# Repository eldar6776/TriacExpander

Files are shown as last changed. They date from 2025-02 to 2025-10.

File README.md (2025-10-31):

# TriacExpander

**RS485 Adresabilni 16-kanalni Triac Ekspander**

## Opis

TriacExpander je hardverski modul i firmware rešenje koje omogućava upravljanje do 16 AC kanala putem RS485 komunikacije. Svaki kanal je kontrolisan pomoću triaka, što omogućava efikasno i bezbedno uključivanje/isključivanje AC potrošača. Adresabilnost modula omogućava povezivanje više ekspandera na istu RS485 magistralu.

## Funkcionalnosti

- **16 nezavisnih AC kanala** – svaki kanal se može pojedinačno uključiti ili isključiti
- **RS485 komunikacija** – robustan i pouzdan industrijski standard za serijsku komunikaciju na duže udaljenosti
- **Adresabilni moduli** – svaki ekspander ima sopstvenu adresu na mreži
- **Podrška za kaskadno povezivanje** – više modula može raditi zajedno
- **Jednostavna integracija** – lako se povezuje sa PLC-om, mikrokontrolerima (npr. Arduino, ESP32), ili PC aplikacijama

## Tehničke karakteristike

- **Napajanje:** 220V AC (za triac kanale), 12V DC (za logiku, zavisno od dizajna)
- **Komunikacija:** RS485 (Modbus RTU ili custom protokol)
- **Broj kanala:** 16
- **Tip triaka:** BT136 ili ekvivalent
- **Maksimalna struja po kanalu:** do 16A (zavisno od triaka i hlađenja)
- **Mikrokontroler:** [STM32F030C6T6]

## Uputstvo za korišćenje

1. **Povezivanje modula**
    - Priključite AC izlaze na željene potrošače (npr. lampe, pumpe, grejače)
    - Povežite RS485 magistralu sa master uređajem (PLC, PC, Arduino...)

2. **Podešavanje adrese**
    - Svaki modul ima jumper/switch za podešavanje adrese (npr. 1-15)
    - Adresa se mora razlikovati za svaki modul na mreži

3. **Komunikacija**
    - Koristite odgovarajući komandni set za uključivanje/isključivanje kanala:
        - `SET <ADRESA> <KANAL> <ON/OFF>`
        - Primer: `SET 02 05 ON` – uključuje kanal 5 na modulu sa adresom 02

4. **Integracija sa softverom**
    - Primer Arduino koda za upravljanje:
    ```cpp
    // Slanje komande preko RS485
    Serial.print("SET 01 03 ON\n");
    ```

## Primeri primene

- Automatizacija rasvete u industriji ili domaćinstvu
- Upravljački sistemi grejanja, ventilacije i klimatizacije (HVAC)
- Kontrola pumpi, ventilatora i drugih električnih uređaja

## Šema povezivanja

*(https://github.com/eldar6776/TriacExpander/blob/main/hw/DE-140824/DE-140824.pdf)*

## Kontakt & Podrška

Za pitanja, sugestije ili podršku, kontaktirajte autora putem GitHub Issues

---

**Napomena:** Prilikom povezivanja AC tereta, obavezno poštujte sigurnosne mere i preporučuje se rad stručnog lica!

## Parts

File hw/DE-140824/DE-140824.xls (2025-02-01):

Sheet: BOM Report
Bill of Materials |  |  | Bill of Materials For PCB Document [DE-140824.PcbDoc]
Source Data From: |  | DE-140824.PcbDoc
Project: |  | DE-140824.PrjPcb
Variant: |  | None
Creation Date: | 14. 8. 2024. | 20:08:16
Print Date: | 45518 | 45518.83924
Footprint | Comment | LibRef | Designator | Description | Quantity
0805 | C0805 | C0805 | C1, C4, C8, C13 | Ceramic Chip Capacitor - Standard | 4
0603 | C0603 | C0603 | C2, C3, C5, C7, C9, C10, C11, C12, C14, C15, C22, C23, C24, C25 | Ceramic Chip Capacitor - Standard | 14
0603 | 100nF | C0603 | C6, C19, C20, C21 | Ceramic Chip Capacitor - Standard | 4
CAPPR5-10X12.5 | 470uF | EKA00DC347E00 | C16, C17 | Aluminum Electrolytic Capacitor, Radial Style with Long Leads: 470uF, 25V | 2
CAPPR2-5X11 | 22uF | EKA00AA247F00 | C18 | Aluminum Electrolytic Capacitor, Radial Style with Long Leads: 47uF, 35V | 1
ONSC-TO-220-3-221A-07 | BTA08-600 | BTA08-600BW3G | D1, D2, D3, D4, D5, D6, D7, D8, D9, D10, D11, D12, D13, D14, D15, D16 | Triacs, Silicon Bidirectional Thyristor, 3-Pin TO-220, Pb-Free, Tube | 16
1.6X0.8X0.8 | LED0 | HSMB-C190 | D17 | Blue Surface Mount Chip LED, Blue | 1
1.6X0.8X0.8 | LED4 | HSMB-C190 | D18 | Blue Surface Mount Chip LED, Blue | 1
1.6X0.8X0.8 | LED8 | HSMB-C190 | D19 | Blue Surface Mount Chip LED, Blue | 1
1.6X0.8X0.8 | LED12 | HSMB-C190 | D20 | Blue Surface Mount Chip LED, Blue | 1
1.6X0.8X0.8 | LED1 | HSMB-C190 | D21 | Blue Surface Mount Chip LED, Blue | 1
1.6X0.8X0.8 | LED5 | HSMB-C190 | D22 | Blue Surface Mount Chip LED, Blue | 1
1.6X0.8X0.8 | LED9 | HSMB-C190 | D23 | Blue Surface Mount Chip LED, Blue | 1
1.6X0.8X0.8 | LED13 | HSMB-C190 | D24 | Blue Surface Mount Chip LED, Blue | 1
1.6X0.8X0.8 | LED2 | HSMB-C190 | D25 | Blue Surface Mount Chip LED, Blue | 1
1.6X0.8X0.8 | LED6 | HSMB-C190 | D26 | Blue Surface Mount Chip LED, Blue | 1
1.6X0.8X0.8 | LED10 | HSMB-C190 | D27 | Blue Surface Mount Chip LED, Blue | 1
1.6X0.8X0.8 | LED14 | HSMB-C190 | D28 | Blue Surface Mount Chip LED, Blue | 1
1.6X0.8X0.8 | LED3 | HSMB-C190 | D29 | Blue Surface Mount Chip LED, Blue | 1
1.6X0.8X0.8 | LED7 | HSMB-C190 | D30 | Blue Surface Mount Chip LED, Blue | 1
1.6X0.8X0.8 | LED11 | HSMB-C190 | D31 | Blue Surface Mount Chip LED, Blue | 1
1.6X0.8X0.8 | LED15 | HSMB-C190 | D32 | Blue Surface Mount Chip LED, Blue | 1
0402-A | BLM15AG121 | Chip inductor | L1, L2, L3 | SMD chip inductor | 3
TERMINAL BLOK 2 | RS485 | TERMINAL BLOK 2 | P1 | Terminal blok konektor 3,5 mm | 1
HDR1X9 | Header 9 | Header 9 | P2, P3, P15, P16 | Header, 9-Pin | 4
TERMINAL BLOK 3 |  | TERMINAL BLOK 3 | P4, P5, P6, P7, P8, P9 | 3 pinski terminal blok konektor | 6
HDR1X3 | ICSP | Header 3 | P10 | Header, 3-Pin | 1
HDR1X12 | Header 12 | Header 12 | P11, P12, P17, P18 | Header, 12-Pin | 4
HDR2X8 | Header 8X2 | Header 8X2 | P13, P19 | Header, 8-Pin, Dual row | 2
TERMINAL BLOK 2 | DC_IN | TERMINAL BLOK 2 | P14 | Terminal blok konektor 3,5 mm | 1
ERA-0603 | 10K | ERAV, ERA3Y, ERA3Y, ERA3Y | R1, R8, R10, R11 | Metal Film Thermosensitive Chip Resistor, 0.56 Ohm to 10k Ohm Range, 5% Tolerance, 0603 Size, 0.063 W, Rectangular Thick Film Chip Resistor, 10 Ohm to 330k Ohm Range, 0.1% and 0.5% Tolerance, 0603 Size, 0.063 W, Rectangular Thick Film Chip Resistor, 10 Oh | 4
ERA-0603 | 10R | ERAV | R2, R3 | Metal Film Thermosensitive Chip Resistor, 0.56 Ohm to 10k Ohm Range, 5% Tolerance, 0603 Size, 0.063 W | 2
ERA-0603 | 1K2 | ERAV | R4 | Metal Film Thermosensitive Chip Resistor, 0.56 Ohm to 10k Ohm Range, 5% Tolerance, 0603 Size, 0.063 W | 1
ERA-0603 | 2K2 | ERAV, ERA3Y, ERA3Y | R5, R6, R7 | Metal Film Thermosensitive Chip Resistor, 0.56 Ohm to 10k Ohm Range, 5% Tolerance, 0603 Size, 0.063 W, Rectangular Thick Film Chip Resistor, 10 Ohm to 330k Ohm Range, 0.1% and 0.5% Tolerance, 0603 Size, 0.063 W, Rectangular Thick Film Chip Resistor, 10 Oh | 3
ERA-0603 | 100R | ERAV | R9, R12 | Metal Film Thermosensitive Chip Resistor, 0.56 Ohm to 10k Ohm Range, 5% Tolerance, 0603 Size, 0.063 W | 2
ERA-0603 | 220R | ERA3Y, ERA3Y, ERA3Y, ERA3Y, ERA3Y, ERA3Y, ERA3Y, ERA3Y, ERA3Y, ERA3Y, ERA3Y, ERA3Y, ERA3Y, ERA3Y, ERA3Y, ERA3Y, ERAS, ERAS, ERAS, ERAS | R13, R17, R23, R27, R33, R37, R43, R47, R53, R57, R63, R67, R73, R77, R83, R87, R93, R94, R95, R96 | Rectangular Thick Film Chip Resistor, 10 Ohm to 330k Ohm Range, 0.1% and 0.5% Tolerance, 0603 Size, 0.063 W, Rectangular Thick Film Chip Resistor, 10 Ohm to 330k Ohm Range, 0.1% and 0.5% Tolerance, 0603 Size, 0.063 W, Rectangular Thick Film Chip Resistor, | 20
ERA-0805 | 120R | ERAS | R14, R15, R16, R18, R19, R20, R24, R25, R26, R28, R29, R30, R34, R35, R36, R38, R39, R40, R44, R45, R46, R48, R49, R50, R54, R55, R56, R58, R59, R60, R64, R65, R66, R68, R69, R70, R74, R75, R76, R78, R79, R80, R84, R85, R86, R88, R89, R90 | Metal Film Thermosensitive Chip Resistor, 0.56 Ohm to 10k Ohm Range, 5% Tolerance, 0805 Size, 0.1 W | 48
ERA-0805 | 330R | ERAS | R21, R22, R31, R32, R41, R42, R51, R52, R61, R62, R71, R72, R81, R82, R91, R92 | Metal Film Thermosensitive Chip Resistor, 0.56 Ohm to 10k Ohm Range, 5% Tolerance, 0805 Size, 0.1 W | 16
DIP-12/SW | SW DIP-6 | SW DIP-6 | S1 | DIP Switch, 6 Position, SPST | 1
TACTILE_SWITCH | MOVE | TACKTILE_SWITCH | S2 |  | 1
TACTILE_SWITCH | FUNC | TACKTILE_SWITCH | S3 |  | 1
STM-LQFP48_N | STM32F030C6T6 | STM32F030C6T6 | U1 | ARM Cortex-M0 32-bit MCU, 32 KB Flash, 4 KB Internal RAM, 39 I/Os, 48-pin LQFP, -40 to 85 degC, Tray | 1
D008_N | SN75176BD | SN75176BD | U2 | Differential Bus Transceiver | 1
SOT-23-OT5_N | 24AA01T-I/OT | 24AA01T-I/OT | U3 | 1Kbit, 400kHz, 1.8V, I2C Serial EEPROM, 5-Pin SOT-23, Industrial Temperature, Tape and Reel | 1
DBZ3_N | TLV803MDBZR | TLV803MDBZR | U4 | Voltage Supervisor with Active-Low, Open Drain Reset, 1 Supply Monitored, -40 to 125 degC, 3-pin SOT-23 (DBZ), Green (RoHS & no Sb/Br) | 1
SOIC-SN8_N | MCS1802GS-10-Z | ACS71240 | U5, U7 |  | 2
TO220 | L7805CV | L7805CV | U6 | Positive Voltage Regulator, 5V, 3-Pin TO-220 | 1
ZZ311 | REG1117-3.3 | REG1117-3.3 | U8 | 800mA and 1A Low Dropout Positive Regulator 2.85V, 3.3V, 5V, and Adjustable | 1
DIP6 | MOC3081 | MOC3081 | U9, U10, U11, U12, U13, U14, U15, U16, U17, U18, U19, U20, U21, U22, U23, U24 | Zero-Cross Optoisolator Triac Driver | 16
 |  |  |  |  | 202
Approved |  | Notes

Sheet: Project Information
Project Full Path | D:\ProjektiOtvoreni\Expanderi\TriacExpander\DE-140824\DE-140824.PrjPcb
Project Filename | DE-140824.PrjPcb
Variant Name | None
Data-Source Filename | DE-140824.PcbDoc
Data-Source Full Path | D:\ProjektiOtvoreni\Expanderi\TriacExpander\DE-140824\DE-140824.PcbDoc
Title | Bill of Materials For PCB Document [DE-140824.PcbDoc]
Total Quantity | 202
Report Time | 20:08:16
Report Date | 14. 8. 2024.
Report Date & Tine | 14. 8. 2024. 20:08:16
Output Name | Bill of Materials
Output Type | BOM_PartType
Output Generator Name | BOM
Output Generator Description | Bill of Materials

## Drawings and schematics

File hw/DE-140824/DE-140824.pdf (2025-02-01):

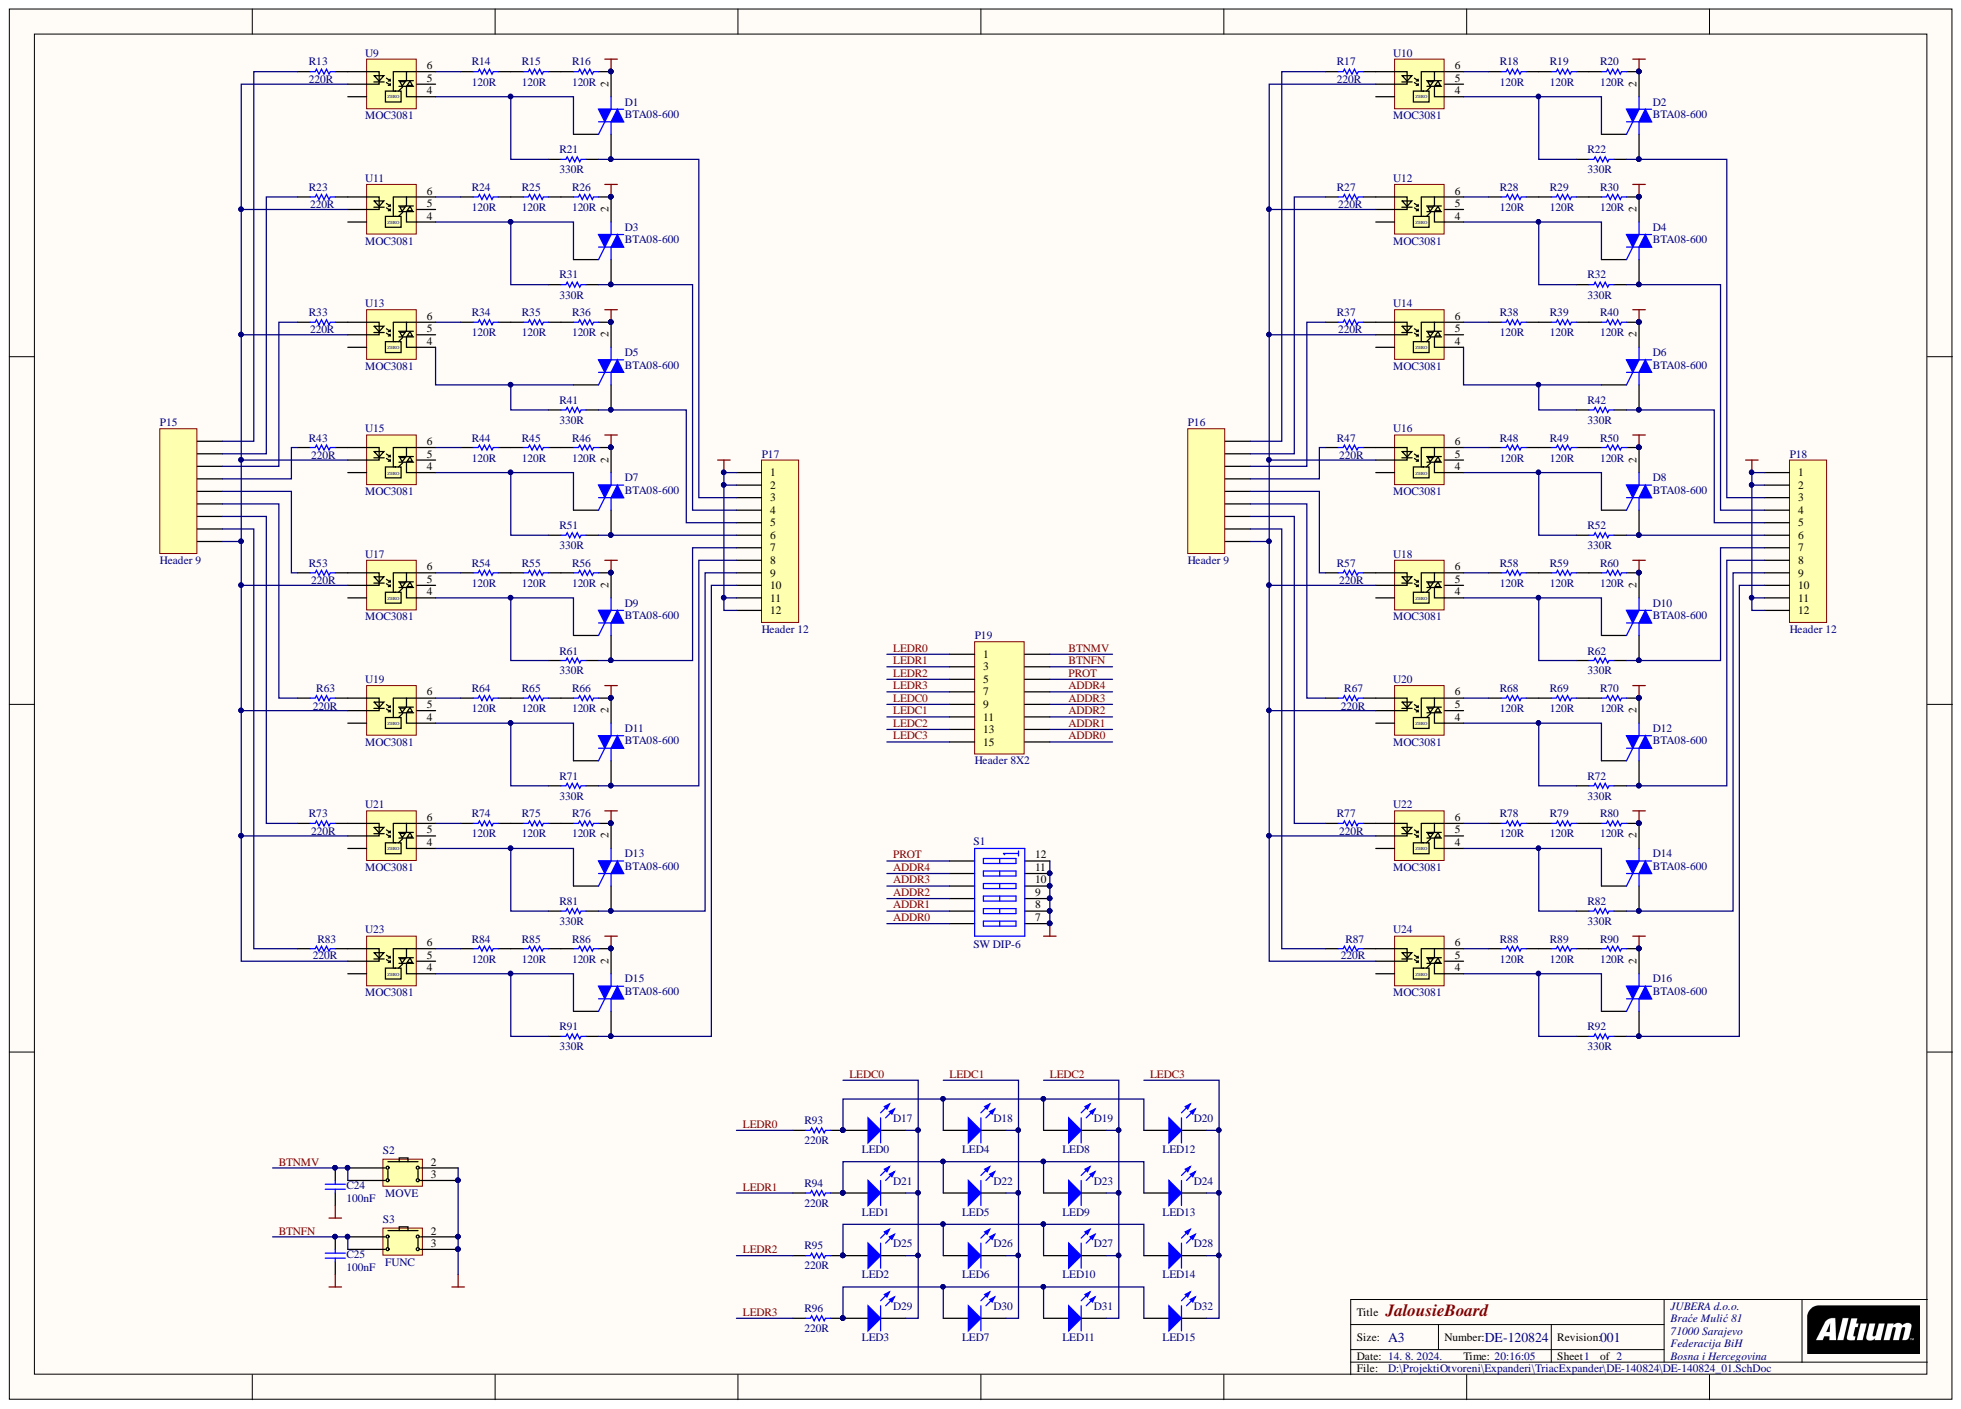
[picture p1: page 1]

JalousieBoard Title | JUBERA d.o.o. Braće Mulić 81 71000 Sarajevo Federacija BiH Bosna i Hercegovina

Size: A3 | Number: DE-120824 | Revision: 001
Date: 14. 8. 2024. Time: 20:16:05 | | Sheet of 2

D:\ProjektiOtvoreni\Expanderi\TriacExpander\DE-140824\DE-140824_01.SchDoc

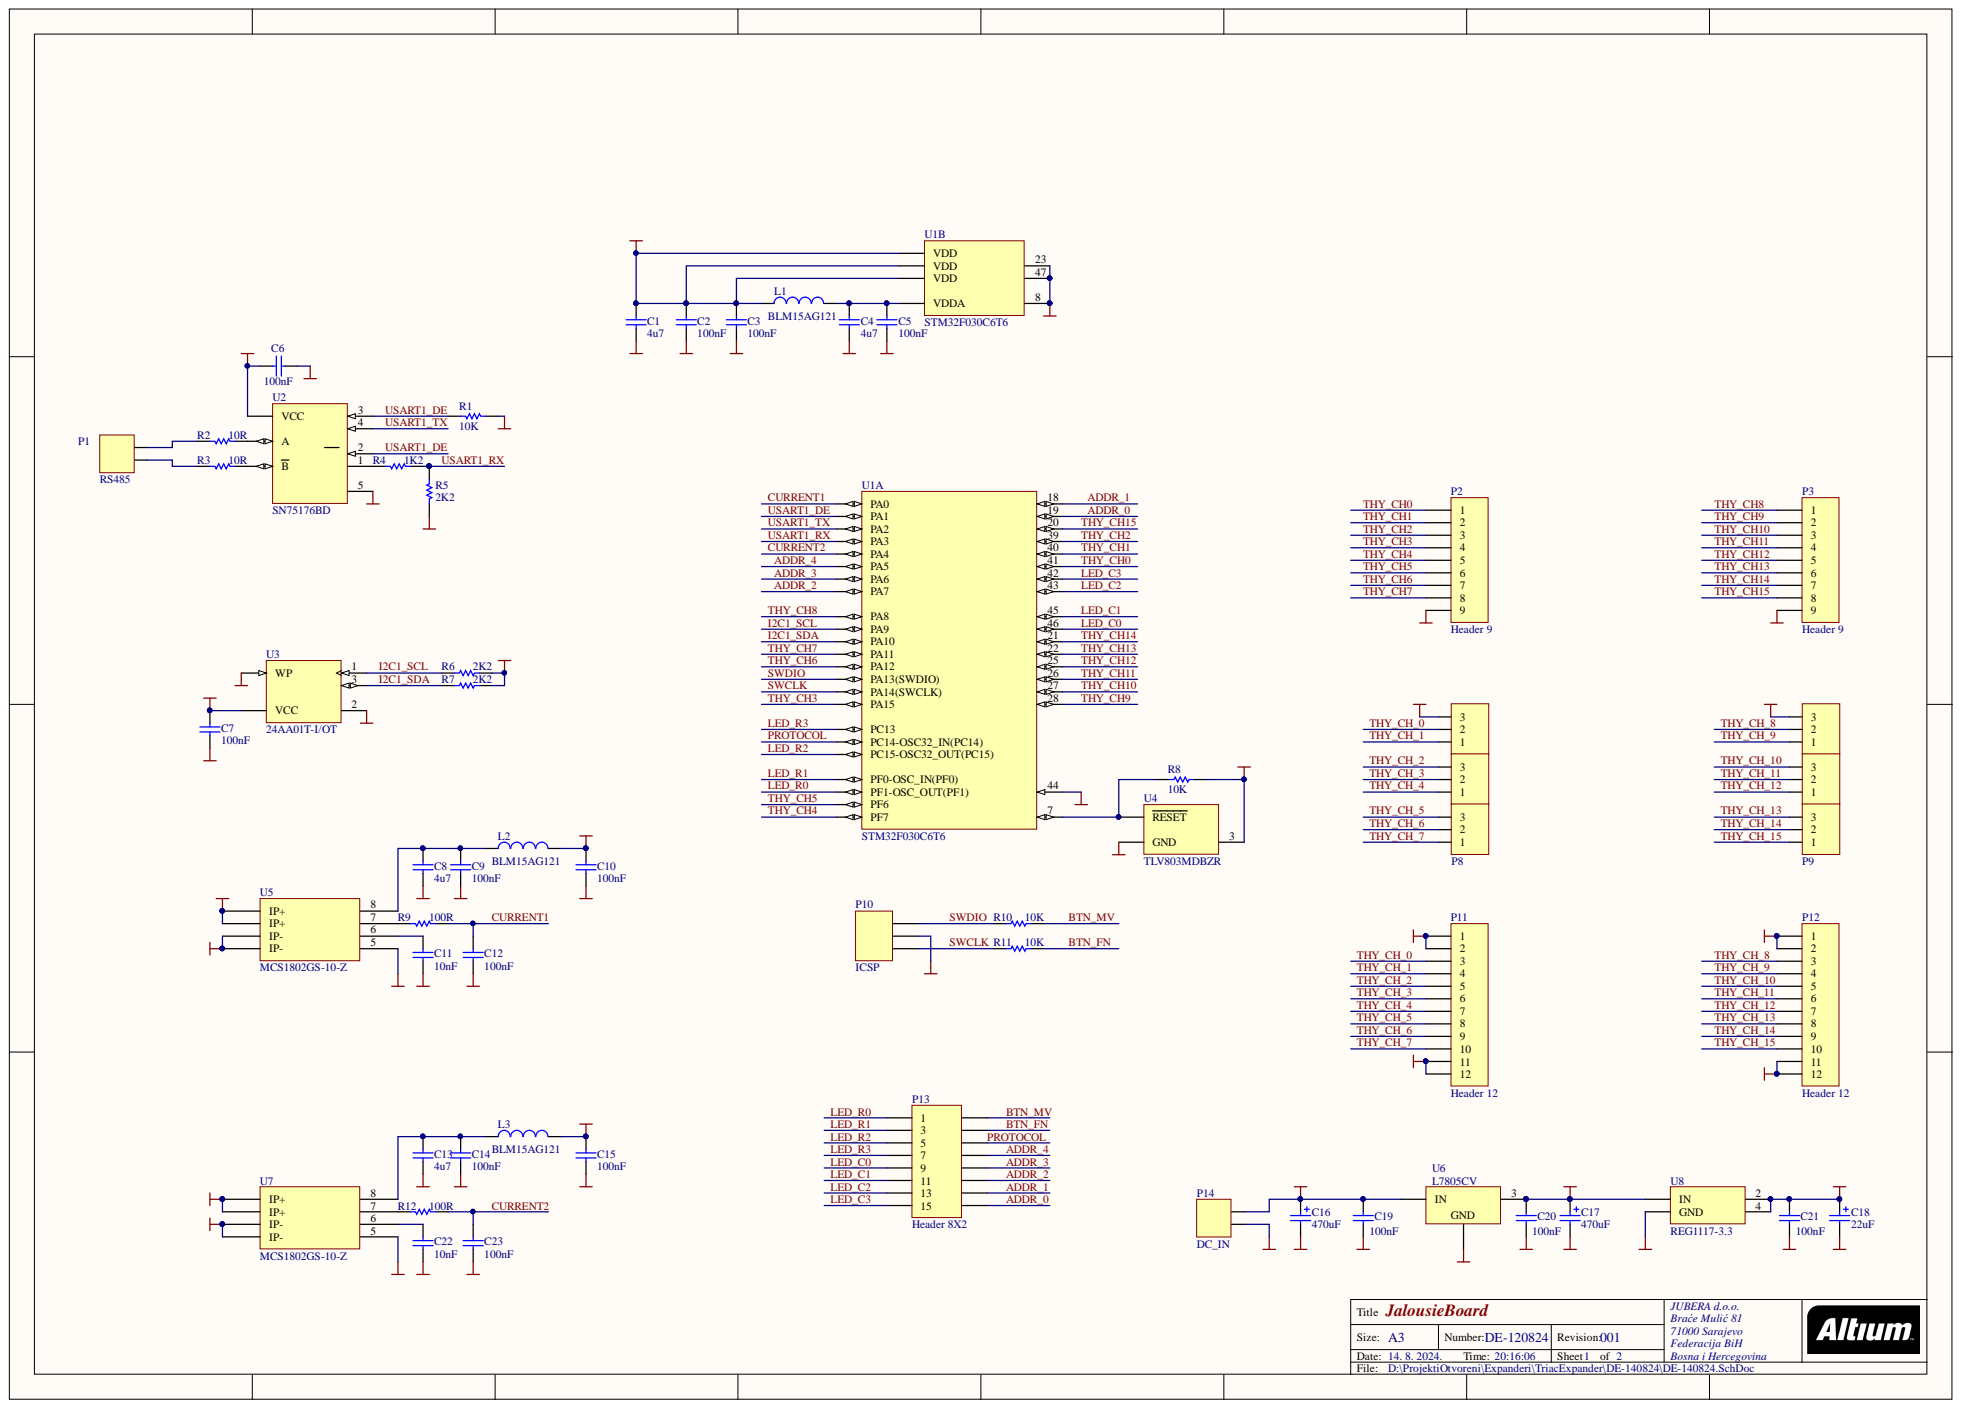
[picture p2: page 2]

Jalou s i Ti t l e | JUB ERA d.o.o. B r a će Mul i ć 81 71000 Sarajevo Federacija BiH Bosna i Hercegovina

Size: A | Number : E-120824 | Revi s ion: 001
Date: Ti me: | | Sheet of

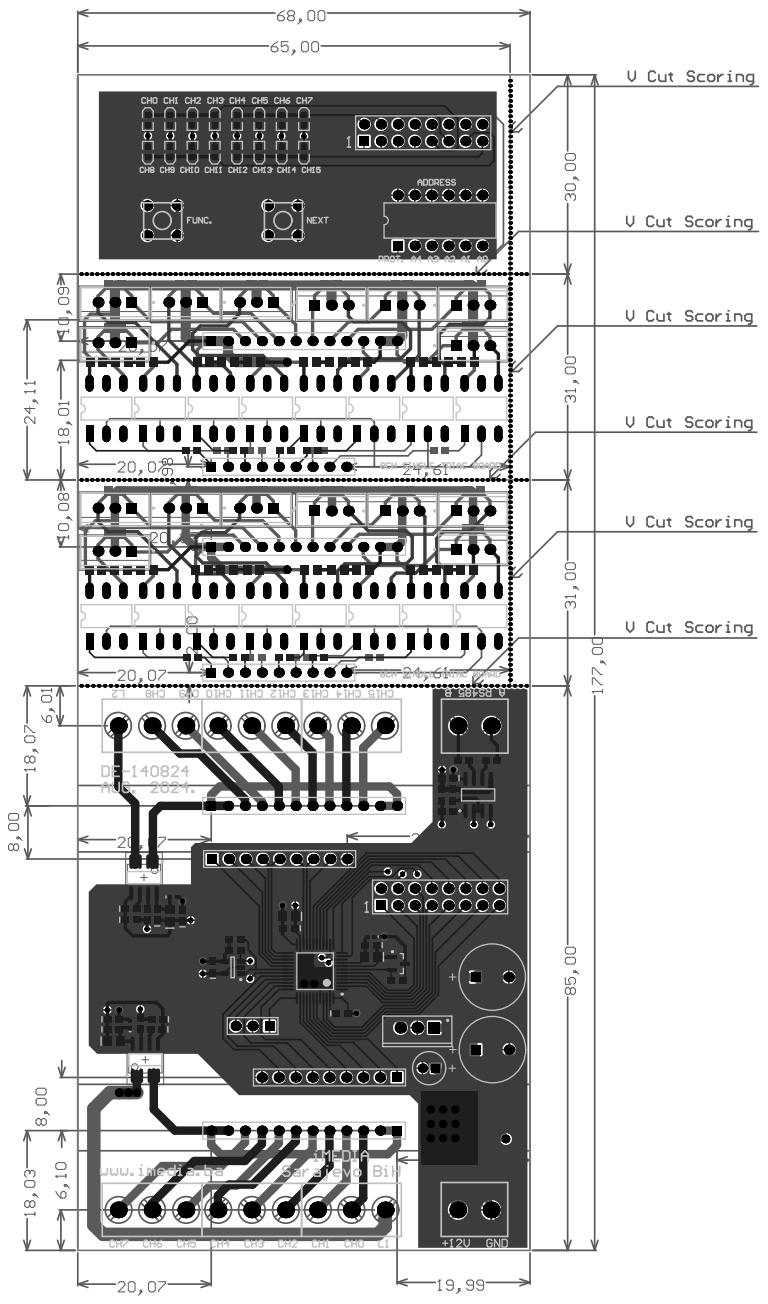
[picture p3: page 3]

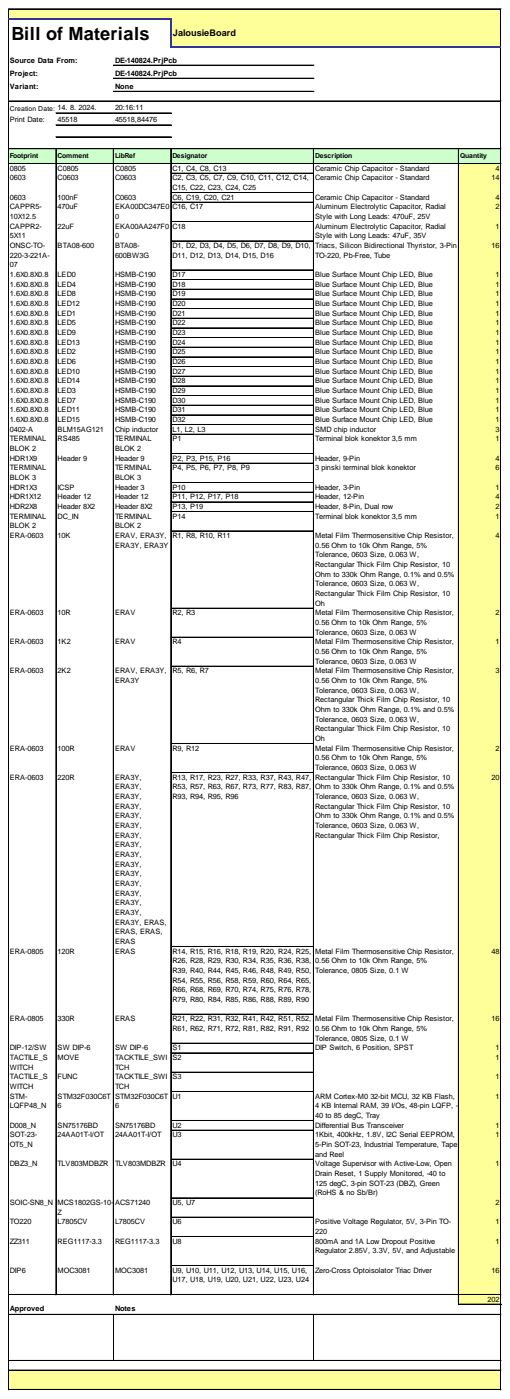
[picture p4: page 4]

Style with Long Leads: 470uF, 25V

Style with Long Leads: 47uF, 35V
Triacs, Silicon Bidirectional Thyristor, 3-Pin
TO-220, Pb-Free, Tube

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

Tolerance, 0603 Size, 0.063 W

Rectangular Thick Film Chip Resistor,

Metal Film Thermosensitive Chip Resistor,
Tolerance, 0805 Size, 0.1 W

4 KB Internal RAM, 39 I/Os, 48-pin LQFP, -
40 to 85 degC, Tray

5-Pin SOT-23, Industrial Temperature, Tape
and Reel

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

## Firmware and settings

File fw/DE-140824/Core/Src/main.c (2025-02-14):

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
/* Includes ------------------------------------------------------------------*/
#include "main.h"

/* USER CODE BEGIN Includes */
#include <stdio.h>
#include <string.h>
#include <stdarg.h>
#include <stdlib.h>
/* USER CODE END Includes */

/* USER CODE BEGIN PD */
#define NUMBER_OF_TRIAC 16
#define SNAKE_LENGTH 4  // Dužina zmije
#define SNAKE_SPEED 20   // Brzina zmije (veća vrednost = sporije)
#define MENU_TIMEOUT    10000 // 10 sekundi timeout
#define BUTTON_PAUSE    200 // dodatni debouncing
#define TOGGLE_INTERVAL 50 // Period treptanja LED
/* USER CODE END PD */

ADC_HandleTypeDef hadc;

CRC_HandleTypeDef hcrc;

I2C_HandleTypeDef hi2c1;

IWDG_HandleTypeDef hiwdg;

TIM_HandleTypeDef htim14;

UART_HandleTypeDef huart1;

/* USER CODE BEGIN PV */
GPIO_TypeDef *TRIAC_PORT[NUMBER_OF_TRIAC] = {GPIOB, GPIOB, GPIOB, GPIOA, GPIOF, GPIOF, GPIOA, GPIOA, GPIOA, GPIOB, GPIOB, GPIOB, GPIOB, GPIOB, GPIOB, GPIOB};
uint16_t GATE_PIN[NUMBER_OF_TRIAC] = {GPIO_PIN_5, GPIO_PIN_4, GPIO_PIN_3, GPIO_PIN_15, GPIO_PIN_7, GPIO_PIN_6 ,GPIO_PIN_12 ,GPIO_PIN_11, GPIO_PIN_8, \
                        GPIO_PIN_15, GPIO_PIN_14, GPIO_PIN_13, GPIO_PIN_12, GPIO_PIN_11, GPIO_PIN_10, GPIO_PIN_2};

volatile uint8_t snake_head = 0;  // Trenutna glava zmije
volatile uint8_t snake_counter = 0;  // Brojač za usporavanje

// Stanje LED dioda (simulacija konstante, treba postavljati u aplikaciji)
volatile uint8_t led_states[NUMBER_OF_TRIAC] = {0};
volatile uint8_t triac_states[NUMBER_OF_TRIAC] = {0};  // Trenutnostanje releja

// Trenutno aktivni red
volatile uint8_t active_row = 0;

volatile uint32_t last_press_time = 0;
volatile uint32_t menu_timer = 0;
volatile uint32_t last_toggle_time = 0;
volatile uint8_t toggle_state = 0;
volatile uint8_t menu_activ = 0;
volatile uint8_t selected_channel = NUMBER_OF_TRIAC - 1;
volatile uint8_t button_select_prev = 0, button_onoff_prev = 0;
volatile uint8_t my_address = 0;
volatile uint8_t first_toggle = 1;
volatile uint16_t triac_start = 0;
volatile uint16_t triac_end = 0;
bool init_tf = false;
bool restart = false;
bool setup_mod = false;
uint8_t rec;
TinyFrame tfapp;
/* USER CODE END PV */

void SystemClock_Config(void);
static void MX_GPIO_Init(void);
static void MX_ADC_Init(void);
static void MX_I2C1_Init(void);
static void MX_IWDG_Init(void);
static void MX_USART1_UART_Init(void);
static void MX_CRC_Init(void);
static void MX_TIM14_Init(void);
/* USER CODE BEGIN PFP */
void RS485_Init(void);
/* USER CODE END PFP */

/* USER CODE BEGIN 0 */
/**
  * @brief  staticka inline funkcija pauze 1~2ms za kašnjenje odgovora za stabilne repeatere
  *         u interruptu se ne može koristiti HAL_GetTick ni HAL_Delay tako da ova funkcija
  *         obezbjeduje kašnjenje oko 1 ms bez hal drivera gubljenjem vremena izvršavanjem 
  *         ciklusa koji ne rade ništa
  * @param
  * @retval
  */
static inline void delay_us(uint32_t us) {
    volatile uint32_t cycles = (HAL_RCC_GetHCLKFreq() / 20000000) * us;  // Smanjen faktor
    while (cycles--) {                                  
        __asm volatile("NOP");  // Izbegava optimizaciju
    }
}
/**
  * @brief Podesi rs485 adresu  uređaja prema poziciji DIP sitcheva
  * @retval None
  */
void get_address(void)
{
    my_address = 0;
    if ((HAL_GPIO_ReadPin(ADDRESS0_GPIO_Port, ADDRESS0_Pin) == GPIO_PIN_RESET))   my_address |= 0x20;
    if ((HAL_GPIO_ReadPin(ADDRESS1_GPIO_Port, ADDRESS1_Pin) == GPIO_PIN_RESET))   my_address |= 0x10;
    if ((HAL_GPIO_ReadPin(ADDRESS2_GPIO_Port, ADDRESS2_Pin) == GPIO_PIN_RESET))   my_address |= 0x08;
    if ((HAL_GPIO_ReadPin(ADDRESS3_GPIO_Port, ADDRESS3_Pin) == GPIO_PIN_RESET))   my_address |= 0x04;
    if ((HAL_GPIO_ReadPin(ADDRESS4_GPIO_Port, ADDRESS4_Pin) == GPIO_PIN_RESET))   my_address |= 0x02;
    if ((HAL_GPIO_ReadPin(ADDRESS5_GPIO_Port, ADDRESS5_Pin) == GPIO_PIN_RESET))   my_address |= 0x01;
    if(my_address)
    {
        triac_start = (NUMBER_OF_TRIAC*(my_address-1))+1;
        triac_end = triac_start + NUMBER_OF_TRIAC - 1;
    }
}
/**
  * @brief LED efect for settings menu
  * @retval None
  */
void update_snake(void) 
{
    if (++snake_counter < SNAKE_SPEED) {
        return;  // Čekamo dok ne prođe dovoljno ciklusa
    }
    snake_counter = 0;  // Reset brojača

    // Očisti prethodno stanje LED-ova
    for (uint8_t i = 0; i < 16; i++) {
        led_states[i] = 0;  // Privremeno uklanjamo const
    }

    // Podesi svetleće LED-ove
    for (uint8_t i = 0; i < SNAKE_LENGTH; i++) {
        int8_t pos = snake_head - i;
        if (pos < 0) pos += 16;  // Omogućava kružno kretanje po matrici
        led_states[pos] = 1;  // Upali LED
    }

    // Pomeraj zmiju napred
    snake_head = (snake_head + 1) % 16;
}
/**
  * @brief Refresh triac gate outputs
  * @retval None
  */
void set_triac(void)
{
    // Samo proleti kroz sve izlaze i postavi stanje prema baferu
    for (uint8_t i = 0; i < NUMBER_OF_TRIAC; i++)
    {
        HAL_GPIO_WritePin(TRIAC_PORT[i], GATE_PIN[i], (triac_states[i] > 0) ? GPIO_PIN_SET : GPIO_PIN_RESET);
    }
}
/**
  * @brief Copy triac states to LED
  * @retval None
  */
void refresh_led(void)
{
    // Samo kopiraj izlaze na LED
    for (uint8_t i = 0; i < NUMBER_OF_TRIAC; i++)
    {
        led_states[i] = triac_states[i];
    }
}
/**
  * @brief Funkcija za osvežavanje LED matrice
  * @retval None
  */
void refresh_led_matrix(void) 
{
    // Isključi trenutno aktivni red
    HAL_GPIO_WritePin(LED_R0_GPIO_Port, LED_R0_Pin, GPIO_PIN_RESET);
    HAL_GPIO_WritePin(LED_R1_GPIO_Port, LED_R1_Pin, GPIO_PIN_RESET);
    HAL_GPIO_WritePin(LED_R2_GPIO_Port, LED_R2_Pin, GPIO_PIN_RESET);
    HAL_GPIO_WritePin(LED_R3_GPIO_Port, LED_R3_Pin, GPIO_PIN_RESET);

    // Očisti kolone
    HAL_GPIO_WritePin(LED_C0_GPIO_Port, LED_C0_Pin, GPIO_PIN_SET);
    HAL_GPIO_WritePin(LED_C1_GPIO_Port, LED_C1_Pin, GPIO_PIN_SET);
    HAL_GPIO_WritePin(LED_C2_GPIO_Port, LED_C2_Pin, GPIO_PIN_SET);
    HAL_GPIO_WritePin(LED_C3_GPIO_Port, LED_C3_Pin, GPIO_PIN_SET);

    // Aktiviraj sledeći red
    switch (active_row) {
    case 0:
        HAL_GPIO_WritePin(LED_R0_GPIO_Port, LED_R0_Pin, GPIO_PIN_SET);
        break;
    case 1:
        HAL_GPIO_WritePin(LED_R1_GPIO_Port, LED_R1_Pin, GPIO_PIN_SET);
        break;
    case 2:
        HAL_GPIO_WritePin(LED_R2_GPIO_Port, LED_R2_Pin, GPIO_PIN_SET);
        break;
    case 3:
        HAL_GPIO_WritePin(LED_R3_GPIO_Port, LED_R3_Pin, GPIO_PIN_SET);
        break;
    }

    // Postavi kolone na osnovu led_state[] tako da se kolone i redovi zamjene
    for (uint8_t row = 0; row < 4; row++) {
        uint8_t index = row * 4 + active_row;  // Zamjeni red i kolonu
        if (led_states[index]) {
            switch (row) {
            case 0:
                HAL_GPIO_WritePin(LED_C0_GPIO_Port, LED_C0_Pin, GPIO_PIN_RESET);
                break;
            case 1:
                HAL_GPIO_WritePin(LED_C1_GPIO_Port, LED_C1_Pin, GPIO_PIN_RESET);
                break;
            case 2:
                HAL_GPIO_WritePin(LED_C2_GPIO_Port, LED_C2_Pin, GPIO_PIN_RESET);
                break;
            case 3:
                HAL_GPIO_WritePin(LED_C3_GPIO_Port, LED_C3_Pin, GPIO_PIN_RESET);
                break;
            }
        }
    }

    // Prebaci na sledeći red
    active_row = (active_row + 1) % 4;
}
/**
  * @brief Front panel taster button processing function
  * @retval None
  */
void handle_buttons(void)
{
    uint32_t current_time = HAL_GetTick();
    uint8_t button_select = HAL_GPIO_ReadPin(GPIOA, GPIO_PIN_14);
    uint8_t button_onoff = HAL_GPIO_ReadPin(GPIOA, GPIO_PIN_13);

    if (button_select == GPIO_PIN_RESET) {
        if (!button_select_prev) {
            button_select_prev = 1; // lock press time load
            menu_activ = 1;
            first_toggle = 1;
            if (++selected_channel >= NUMBER_OF_TRIAC) selected_channel = 0;
            toggle_state = triac_states[selected_channel]; // Resetuj toggle_state po novom kanalu
            menu_timer = current_time + MENU_TIMEOUT;
            last_press_time = current_time; // load first press time
            refresh_led();
            get_address(); // ponovo uzmi adresu
            HAL_Delay(BUTTON_PAUSE);
        }
    }
    else if ((button_select == GPIO_PIN_SET) && button_select_prev)
    {
        button_select_prev = 0;
        HAL_Delay(BUTTON_PAUSE);
        refresh_led();
    }

    if (menu_activ && (button_onoff == GPIO_PIN_RESET)) {
        if (!button_onoff_prev) {
            button_onoff_prev = 1; // lock press time load
            last_press_time = current_time; // load first press time
            triac_states[selected_channel] ^= 1; // Toggle stanja triaka

            // Resetujemo first_toggle i toggle_state kako bi ispravno započelo treperenje
            first_toggle = 1;
            toggle_state = triac_states[selected_channel]; 
            HAL_Delay(BUTTON_PAUSE);
            refresh_led();
        }
        menu_timer = current_time + MENU_TIMEOUT;
    }
    else if ((button_onoff == GPIO_PIN_SET) && button_onoff_prev)
    {
        button_onoff_prev = 0; // release button press
        HAL_Delay(BUTTON_PAUSE);
    }
}
/**
  * @brief Jednostavan meni za podešavanje stanja izlaza sa različitim odnosom pauze i signala
  *         odabrane LED prema stanju izlaza kraći signal duža pauza za isključen izlaz    
  * @retval None
  */
void menu_logic(void)
{
    uint32_t current_time = HAL_GetTick();

    // Resetujemo meni ako istekne vrijeme
    if (current_time > menu_timer) {
        selected_channel = NUMBER_OF_TRIAC - 1;
        menu_activ = 0;
        toggle_state = 0;
        refresh_led();
        first_toggle = 1;  // Resetuj first_toggle ako se resetuje meni
    }

    // Definiši vremenske intervale zavisno od triac_states
    uint32_t on_time, off_time;
    if (triac_states[selected_channel] == 1) {
        on_time = TOGGLE_INTERVAL * 5;  // LED ON duže
        off_time = TOGGLE_INTERVAL;     // LED OFF kraće
    } else {
        on_time = TOGGLE_INTERVAL;      // LED ON kraće
        off_time = TOGGLE_INTERVAL * 5; // LED OFF duže
    }

    // Pri prvom ulasku postavi početno stanje
    if (first_toggle) {
        toggle_state = triac_states[selected_channel]; // Ako je triac_state 1, LED počinje upaljena
        last_toggle_time = current_time;  // Resetujemo timer
        first_toggle = 0; // Obilježimo da više nije prvi ulazak
    }

    // Odredi trenutno trajanje na osnovu toggle_state
    uint32_t toggle_period = toggle_state ? on_time : off_time;

    // Ako je prošao period, promjeni stanje
    if (current_time - last_toggle_time >= toggle_period) {
        led_states[selected_channel] ^= 1;  // Toggler LED stanje
        toggle_state = !toggle_state;       // Promjena stanja za sljedeći ciklus
        last_toggle_time = current_time;    // Ažuriraj vrijeme zadnjeg toggle-a
    }
}
/**
  * @brief LED efect for settings menu
  * @retval None
  */
void start_effect(void)
{
    setup_mod = true;
    HAL_Delay(1200);
#ifdef USE_WATCHDOG
    HAL_IWDG_Refresh(&hiwdg);
#endif
    HAL_Delay(1200);
#ifdef USE_WATCHDOG
    HAL_IWDG_Refresh(&hiwdg);
#endif
    HAL_Delay(1200);
#ifdef USE_WATCHDOG
    HAL_IWDG_Refresh(&hiwdg);
#endif
    setup_mod = false;
    for (uint8_t i = 0; i < NUMBER_OF_TRIAC; i++)
    {
        led_states[i] = 0;
    }
HAL_Delay(100);
#ifdef USE_WATCHDOG
    HAL_IWDG_Refresh(&hiwdg);
#endif
    for (uint8_t i = 0; i < NUMBER_OF_TRIAC; i++)
    {
        led_states[i] = 1;
    }
HAL_Delay(100);
#ifdef USE_WATCHDOG
    HAL_IWDG_Refresh(&hiwdg);
#endif
    for (uint8_t i = 0; i < NUMBER_OF_TRIAC; i++)
    {
        led_states[i] = 0;
    }
HAL_Delay(100);
#ifdef USE_WATCHDOG
    HAL_IWDG_Refresh(&hiwdg);
#endif
    for (uint8_t i = 0; i < NUMBER_OF_TRIAC; i++)
    {
        led_states[i] = 1;
    }
HAL_Delay(100);
#ifdef USE_WATCHDOG
    HAL_IWDG_Refresh(&hiwdg);
#endif
    for (uint8_t i = 0; i < NUMBER_OF_TRIAC; i++)
    {
        led_states[i] = 0;
    }
HAL_Delay(100);
#ifdef USE_WATCHDOG
    HAL_IWDG_Refresh(&hiwdg);
#endif
    for (uint8_t i = 0; i < NUMBER_OF_TRIAC; i++)
    {
        led_states[i] = 1;
    }
HAL_Delay(100);
#ifdef USE_WATCHDOG
    HAL_IWDG_Refresh(&hiwdg);
#endif
    for (uint8_t i = 0; i < NUMBER_OF_TRIAC; i++)
    {
        led_states[i] = 0;
    }
}
/* USER CODE END 0 */

/**
  * @brief  The application entry point.
  * @retval int
  */
int main(void)
{

    /* MCU Configuration--------------------------------------------------------*/

    /* Reset of all peripherals, Initializes the Flash interface and the Systick. */
    HAL_Init();

    /* Configure the system clock */
    SystemClock_Config();

    /* Initialize all configured peripherals */
    MX_GPIO_Init();
    MX_ADC_Init();
    MX_I2C1_Init();
    MX_IWDG_Init();
    MX_USART1_UART_Init();
    MX_CRC_Init();
    MX_TIM14_Init();
    /* USER CODE BEGIN 2 */
    RS485_Init();
    get_address();
    start_effect();
    /* USER CODE END 2 */

    /* Infinite loop */
    /* USER CODE BEGIN WHILE */
    while (1)
    {
        if(restart == true) Error_Handler(); // resetuj modul ako je flag dignut
#ifndef USE_DEBUGGER
        handle_buttons();
        menu_logic();
#endif
        /* USER CODE END WHILE */

        /* USER CODE BEGIN 3 */
        set_triac();
        
#ifdef USE_WATCHDOG
        HAL_IWDG_Refresh(&hiwdg);
#endif
    }
    /* USER CODE END 3 */
}

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
/* USER CODE BEGIN 4 */
// Timer interrupt callback
void HAL_TIM_PeriodElapsedCallback(TIM_HandleTypeDef *htim) 
{
    if (htim->Instance == TIM14) {
        if(setup_mod == true) update_snake();  // Ažuriraj stanje zmije ako je mod podešavanja aktivan
        refresh_led_matrix();
    }
}
/**
  * @brief  Sluša bus za paket sa BINARY_SET tipom i provjerava adresirani izlaz 
  *         ako je u sopstvenom opsegu reaguje na ostale ne odgovara
  * @param
  * @retval
  */
TF_Result BINARY_SET_Listener(TinyFrame *tf, TF_Msg *msg)
{
    uint8_t res = 0;
    uint16_t adr = (uint16_t) (msg->data[0] << 8) | msg->data[1]; // Kombinacija dva bajta u adresu
    uint8_t idx = adr - triac_start; // Izračunavanje indeksa triaka
    uint8_t ret[4]; // Niz za vraćanje stanja

    // Provjeravamo da li je adresa unutar opsega triac_start i triac_end
    if (adr && my_address && (adr >= triac_start) && (adr <= triac_end)) {
        if (msg->data[2] == 0x01) {
            triac_states[idx] = 1;  // Uključivanje triaka
        } else if (msg->data[2] == 0x02) {
            triac_states[idx] = 0;  // Isključivanje triaka
        }
        refresh_led();
        res++;  // Povećavamo broj uspešnih operacija
    }

    // Ako je došlo do promene stanja, vraćamo novo stanje
    if (res == 1) {
        ret[0] = msg->data[0];
        ret[1] = msg->data[1];
        if (triac_states[idx] == 1) {
            ret[2] = 1;  // Stanje 1 (ON)
        } else {
            ret[2] = 2;  // Stanje 2 (OFF)
        }
        ret[3] = ACK; // Dodaj bajt potvrde
        msg->data = ret;  // Postavljamo novi niz za odgovor
        msg->len = 4;  // Dužina odgovora je 4 bajta
        TF_Respond(tf, msg);  // Odgovaramo sa novim stanjem
    }

    return TF_STAY;  // Održavanje trenutnog stanja
}
/**
  * @brief  Sluša bus za paket sa BINARY_GET tipom i provjerava adresirani izlaz 
  *         ako je u sopstvenom opsegu odgovara sa stanjem na ostale ne odgovara
  * @param
  * @retval
  */
TF_Result BINARY_GET_Listener(TinyFrame *tf, TF_Msg *msg)
{
    uint16_t adr = (uint16_t) (msg->data[0] << 8) | msg->data[1]; // Kombinacija dva bajta u adresu
    uint8_t idx = adr - triac_start; // Izračunavanje indeksa triaka
    uint8_t ret[3]; // Niz za vraćanje stanja

    // Proveravamo da li je adresa unutar opsega rel_start i rel_end
    if (adr && my_address && (adr >= triac_start) && (adr <= triac_end)) {
        // Vraćamo stanje releja na toj adresi
        ret[0] = msg->data[0];
        ret[1] = msg->data[1];
        if (triac_states[idx] == 1) {
            ret[2] = 1;  // Stanje 1 (ON)
        } else {
            ret[2] = 2;  // Stanje 2 (OFF)
        }
        msg->data = ret;  // Postavljamo novi niz sa stanjem releja
        msg->len = 3;  // Dužina odgovora je 3 bajta
        TF_Respond(tf, msg);  // Odgovaramo sa stanjem releja
    }

    return TF_STAY;  // Održavanje trenutnog stanja
}
/**
  * @brief  Sluša bus za paket sa BINARY_RESET tipom i provjerava adresirani izlaz 
  *         ako je u sopstvenom opsegu setuje flag odgovara i nakon odogovora pokreće reset
  * @param
  * @retval
  */
TF_Result BINARY_RESET_Listener(TinyFrame *tf, TF_Msg *msg)
{
    uint16_t adr = (uint16_t) (msg->data[0] << 8) | msg->data[1]; // Kombinacija dva bajta u adresu
    uint8_t idx = adr - triac_start; // Izračunavanje indeksa triaka
    uint8_t ret[3]; // Niz za vraćanje stanja

    // Proveravamo da li je adresa unutar opsega rel_start i rel_end
    if (adr && my_address && (adr >= triac_start) && (adr <= triac_end)) {
        restart = true; // setujemo flag a ne restartujemo odmah da bi vratili odgovor
        // Vraćamo ACK
        ret[0] = msg->data[0];
        ret[1] = msg->data[1];
        ret[2] = ACK;
        msg->data = ret;  // Postavljamo novi niz sa stanjem releja
        msg->len = 3;  // Dužina odgovora je 3 bajta
        TF_Respond(tf, msg);  // Odgovaramo sa stanjem releja
    }

    return TF_STAY;  // Održavanje trenutnog stanja
}
/**
  * @brief
  * @param
  * @retval
  */
void RS485_Init(void)
{
    if(!init_tf) {
        init_tf = TF_InitStatic(&tfapp, TF_SLAVE);
        TF_AddTypeListener(&tfapp, BINARY_GET, BINARY_GET_Listener);
        TF_AddTypeListener(&tfapp, BINARY_SET, BINARY_SET_Listener);
        TF_AddTypeListener(&tfapp, BINARY_RESET, BINARY_RESET_Listener);
    }
    HAL_UART_Receive_IT(&huart1, &rec, 1);
}
/**
  * @brief
  * @param
  * @retval
  */
void RS485_Tick(void)
{
    if (init_tf == true) {
        TF_Tick(&tfapp);
    }
}
/**
  * @brief
  * @param
  * @retval
  */
void TF_WriteImpl(TinyFrame *tf, const uint8_t *buff, uint32_t len)
{
    delay_us(2000); // puza kod odgovora zbog repeatera na linji 
    HAL_UART_Transmit(&huart1,(uint8_t*)buff, len, RESP_TOUT);
    HAL_UART_Receive_IT(&huart1, &rec, 1);
}
/**
  * @brief
  * @param
  * @retval
  */
void HAL_UART_RxCpltCallback(UART_HandleTypeDef *huart)
{
    TF_AcceptChar(&tfapp, rec);
    HAL_UART_Receive_IT(&huart1, &rec, 1);
}
/**
  * @brief
  * @param
  * @retval
  */
void HAL_UART_TxCpltCallback(UART_HandleTypeDef *huart)
{
}
/**
  * @brief
  * @param
  * @retval
  */
void HAL_UART_ErrorCallback(UART_HandleTypeDef *huart)
{
    __HAL_UART_CLEAR_PEFLAG(&huart1);
    __HAL_UART_CLEAR_FEFLAG(&huart1);
    __HAL_UART_CLEAR_NEFLAG(&huart1);
    __HAL_UART_CLEAR_IDLEFLAG(&huart1);
    __HAL_UART_CLEAR_OREFLAG(&huart1);
    HAL_UART_AbortReceive(&huart1);
    HAL_UART_Receive_IT(&huart1, &rec, 1);
}
/* USER CODE END 4 */
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


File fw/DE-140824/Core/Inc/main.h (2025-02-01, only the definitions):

#define LED_R3_Pin GPIO_PIN_13
#define LED_R3_GPIO_Port GPIOC
#define ADDRESS5_Pin GPIO_PIN_14
#define ADDRESS5_GPIO_Port GPIOC
#define LED_R2_Pin GPIO_PIN_15
#define LED_R2_GPIO_Port GPIOC
#define LED_R1_Pin GPIO_PIN_0
#define LED_R1_GPIO_Port GPIOF
#define LED_R0_Pin GPIO_PIN_1
#define LED_R0_GPIO_Port GPIOF
#define CURRENT1_Pin GPIO_PIN_0
#define CURRENT1_GPIO_Port GPIOA
#define CURRENT2_Pin GPIO_PIN_4
#define CURRENT2_GPIO_Port GPIOA
#define ADDRESS4_Pin GPIO_PIN_5
#define ADDRESS4_GPIO_Port GPIOA
#define ADDRESS3_Pin GPIO_PIN_6
#define ADDRESS3_GPIO_Port GPIOA
#define ADDRESS2_Pin GPIO_PIN_7
#define ADDRESS2_GPIO_Port GPIOA
#define ADDRESS1_Pin GPIO_PIN_0
#define ADDRESS1_GPIO_Port GPIOB
#define ADDRESS0_Pin GPIO_PIN_1
#define ADDRESS0_GPIO_Port GPIOB
#define THY_GATE15_Pin GPIO_PIN_2
#define THY_GATE15_GPIO_Port GPIOB
#define THY_GATE14_Pin GPIO_PIN_10
#define THY_GATE14_GPIO_Port GPIOB
#define THY_GATE13_Pin GPIO_PIN_11
#define THY_GATE13_GPIO_Port GPIOB
#define THY_GATE12_Pin GPIO_PIN_12
#define THY_GATE12_GPIO_Port GPIOB
#define THY_GATE11_Pin GPIO_PIN_13
#define THY_GATE11_GPIO_Port GPIOB
#define THY_GATE10_Pin GPIO_PIN_14
#define THY_GATE10_GPIO_Port GPIOB
#define THY_GATE9_Pin GPIO_PIN_15
#define THY_GATE9_GPIO_Port GPIOB
#define THY_GATE8_Pin GPIO_PIN_8
#define THY_GATE8_GPIO_Port GPIOA
#define THY_GATE7_Pin GPIO_PIN_11
#define THY_GATE7_GPIO_Port GPIOA
#define THY_GATE6_Pin GPIO_PIN_12
#define THY_GATE6_GPIO_Port GPIOA
#define THY_GATE5_Pin GPIO_PIN_6
#define THY_GATE5_GPIO_Port GPIOF
#define THY_GATE4_Pin GPIO_PIN_7
#define THY_GATE4_GPIO_Port GPIOF
#define THY_GATE3_Pin GPIO_PIN_15
#define THY_GATE3_GPIO_Port GPIOA
#define THY_GATE2_Pin GPIO_PIN_3
#define THY_GATE2_GPIO_Port GPIOB
#define THY_GATE1_Pin GPIO_PIN_4
#define THY_GATE1_GPIO_Port GPIOB
#define THY_GATE0_Pin GPIO_PIN_5
#define THY_GATE0_GPIO_Port GPIOB
#define LED_C3_Pin GPIO_PIN_6
#define LED_C3_GPIO_Port GPIOB
#define LED_C2_Pin GPIO_PIN_7
#define LED_C2_GPIO_Port GPIOB
#define LED_C1_Pin GPIO_PIN_8
#define LED_C1_GPIO_Port GPIOB
#define LED_C0_Pin GPIO_PIN_9
#define LED_C0_GPIO_Port GPIOB

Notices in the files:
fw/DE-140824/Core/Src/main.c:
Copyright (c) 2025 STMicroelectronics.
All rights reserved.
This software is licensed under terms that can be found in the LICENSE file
